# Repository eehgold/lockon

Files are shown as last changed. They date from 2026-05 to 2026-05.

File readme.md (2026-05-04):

# L.O.C.K.O.N
# Laser Optimized Capture & Kinetic Observation Node

## Objectif

LOCKON est une tourelle motorisee capable de :

- detecter une cible via vision par ordinateur
- suivre automatiquement la cible (tracking)
- orienter une camera sur 2 axes (pan / tilt)
- activer un laser lorsque la cible est verrouillee

---

## Fonctionnement

1. La camera envoie le flux video au PC
2. Le module de vision detecte la cible
3. Le programme calcule la position de la cible
4. Envoi des angles a l'Arduino
5. L'Arduino pilote les servos via le PCA9685
6. Le laser s'allume lorsque la cible est centree

---

## Architecture

## Materiel

### Vision
- Camera USB OV9732 (100 degres, 720p, global shutter)

### Mecanique
- Support pan-tilt aluminium 2 axes
- 2 servos 20 kg

### Electronique
- Arduino Nano (ATmega328)
- Driver PWM PCA9685 (16 canaux)
- Alimentation 5V 5A
- Module laser 5V (650 nm)
- Transistor NPN type 2N2222/BC337 ou MOSFET logique pour commuter le laser
- Resistance 1 kOhm pour la commande du transistor
- Resistance 10 kOhm optionnelle entre commande laser et GND pour garder le laser eteint au demarrage
- Condensateur 470 uF

### Divers
- Cables Dupont
- Visserie / entretoises

---

### Branchements

Etat actuel : l'Arduino est branche au PC en USB. Le PCA9685 est relie a
l'Arduino pour l'I2C et l'alimentation logique. La carte PCA9685 recoit aussi
une alimentation 5V cote servos.

```mermaid
flowchart LR
    PC[PC]
    ARD[Arduino Nano]
    PCA[PCA9685]
    PSU[Alimentation 5V externe]
    S1[Servo axe Y]
    S2[Servo axe X]
    Q1[Transistor/MOSFET]
    LASER[Module laser 5V]

    PC -->|USB| ARD

    ARD -->|A4 / SDA| PCA
    ARD -->|A5 / SCL| PCA
    ARD -->|GND| PCA
    ARD -->|+5V / VCC logique| PCA

    PSU -->|+5V / V+ servos| PCA
    PSU -->|GND commun| PCA

    PCA -->|Canal PWM 0 / axe Y| S1
    PCA -->|Canal PWM 1 / axe X| S2

    ARD -->|D7 via resistance 1k| Q1
    PSU -->|+5V| LASER
    LASER -->|fil noir / GND commute| Q1
    Q1 -->|GND commun| PSU
```

| Arduino Nano | PCA9685 | Role |
| --- | --- | --- |
| A4 | SDA | Donnees I2C |
| A5 | SCL | Horloge I2C |
| GND | GND | Masse commune |
| +5V | VCC | Alimentation logique du PCA9685 |

| Alimentation externe 5V | PCA9685 | Role |
| --- | --- | --- |
| +5V | V+ | Alimentation des servos |
| GND | GND | Masse commune avec Arduino/PCA |

### Branchement du laser

Le module laser a deux fils :

| Fil laser | Branchement recommande | Role |
| --- | --- | --- |
| Rouge | +5V de l'alimentation externe | Alimentation laser |
| Noir | Collecteur/drain du transistor | Masse commutee par l'Arduino |

Commande du transistor :

| Arduino Nano | Intermediaire | Role |
| --- | --- | --- |
| D7 | Resistance 1 kOhm puis base/gate transistor | Signal de commande laser |
| GND | Emetteur/source transistor et GND alimentation | Masse commune |

Avec un NPN type 2N2222/BC337 : fil noir du laser sur le collecteur, emetteur
sur GND, D7 vers la base via une resistance 1 kOhm. Avec un MOSFET logique :
fil noir du laser sur le drain, source sur GND, D7 vers la gate. Dans tous les
cas, le GND Arduino, le GND PCA9685 et le GND de l'alimentation 5V doivent etre
communs.

Ne pas alimenter un laser de courant inconnu directement depuis une broche de
l'Arduino. La broche D7 sert seulement a commander le transistor. Pour les
tests, garder le laser pointe vers une surface mate non reflechissante, jamais
vers les yeux ou un visage.

---

## Test et debug des servos

Le sketch `esp32_prog/esp32_prog.ino` est un sketch de diagnostic pour tester le
PCA9685 et les deux servos.

### Procedure

1. Brancher uniquement Arduino + PCA9685, sans servo.
2. Televerser le sketch Arduino.
3. Ouvrir le moniteur serie en `115200 bauds`.
4. Verifier que le message `PCA9685 detecte a l'adresse 0x40.` apparait.
5. Couper l'alimentation.
6. Brancher un seul servo sur le canal `0`.
7. Remettre l'alimentation 5V externe du PCA9685.
8. Verifier que le servo bouge entre centre, min et max.
9. Couper l'alimentation, puis brancher le deuxieme servo sur le canal `1`.
10. Relancer le test avec les deux servos.

### Points a verifier si rien ne bouge

- Le PCA9685 doit etre detecte sur l'I2C, normalement a l'adresse `0x40`.
- Si le moniteur serie affiche seulement l'en-tete puis plus rien, le programme
  bloque probablement pendant une transaction I2C. Verifier surtout `SDA`,
  `SCL`, `VCC`, `GND`, et retirer temporairement les servos.
- `GND Arduino`, `GND PCA9685` et `GND alimentation servos` doivent etre communs.
- Les servos ne doivent pas etre alimentes par le `5V` de l'Arduino.
- Le bornier `V+` du PCA9685 doit recevoir le `+5V` de l'alimentation externe.
- Le connecteur servo doit etre dans le bon sens : signal PWM, `V+`, `GND`.
- Tester d'abord un seul servo pour eviter une chute de tension.
- Si le servo grogne mais ne tourne pas, verifier l'alimentation 5V et le courant disponible.
- Si le moniteur serie affiche `PCA9685 absent`, verifier `A4/SDA`, `A5/SCL`, `VCC` et `GND`.

### Canaux utilises

| Canal PCA9685 | Role |
| --- | --- |
| 0 | Servo axe Y |
| 1 | Servo axe X |

---

## LOCKON v0.2 - Interface manuelle avec retour camera

Le script `lockon_gui.py` fournit une interface graphique simple pour piloter
les deux servos depuis le PC et afficher le retour de la camera USB.

### Lancement

```powershell
python -m pip install -r requirements.txt
python lockon_gui.py
```

### Fonctionnalites

- Affichage du flux camera dans l'encart `Video`.
- Demarrage automatique de la camera a l'ouverture de la GUI.
- Selection de l'index camera puis demarrage/arret manuel depuis la GUI.
- Detection de cible dans le flux video : `Main` avec le modele local
  `hand_landmarker.task`, ou `Tete` avec la cascade OpenCV integree.
- Overlay LOCKON : reticule central, boite/squelette de cible et compteur.
- Encart `Tracking` avec choix de cible `Rien`, `Main`, `Tete`, mode de vitesse
  `Normal` ou `Fast`, zone morte, gain de correction et prediction.
- Suivi automatique : la tourelle corrige `X/Y` pour ramener la cible au centre
  du reticule.
- Interface regroupee par encarts : `Video`, `Connexion`, `Controles`,
  `Parametres`, `Etat`.
- Connexion au port serie de l'Arduino.
- Affichage de 4 boutons directionnels.
- Pilotage a la souris via les boutons de l'interface.
- Pilotage au clavier avec les touches flechees.
- Affichage de `Pos X` et `Pos Y`.
- Parametre `Vitesse` saisissable puis applique avec le bouton `Envoyer`.
- Affichage de la vitesse appliquee dans la zone `Etat`.
- Bouton `CENTRE` pour revenir a `X=0`, `Y=0`.

La vitesse GUI vaut `50` par defaut et accepte une valeur de `1` a `500`. Cette limite vient de la
datasheet du MG996R, qui annonce environ `0.17 s / 60 degres` a `4.8V` et
`0.14 s / 60 degres` a `6V`.

Le suivi automatique est regle sur `Main` au demarrage. Pour couper totalement
le tracking, choisir `Rien` dans l'encart `Tracking`. Procedure conseillee :
connecter l'Arduino, cliquer `CENTRE`, verifier la detection dans la video, puis
choisir `Main` ou `Tete`. Les boutons manuels gardent la priorite pendant
l'appui. Le mode `Fast` augmente la correction par tick sans depasser les
limites servo.

L'option `Prediction` estime la vitesse de la cible entre deux detections et
oriente le tracking vers une position avancee de quelques millisecondes. Le
parametre `Avance ms` regle cette anticipation. Une valeur trop haute peut
faire depasser la cible ou provoquer des oscillations ; commencer autour de
`160 ms`, puis ajuster progressivement.

### Protocole serie

Le PC envoie des commandes texte a l'Arduino :

```text
POS x y
LASER 0
LASER 1
```

Exemple :

```text
POS 20 -10
LASER 1
```

La GUI v0.2 limite les positions envoyees de `-700` a `700` pour eviter de
forcer les servos en butee pendant les tests. L'Arduino convertit directement la
position en microsecondes autour du centre `1500us` :

```text
pulse servo = 1500us + position
```

Le sketch Arduino accepte encore la plage large historique, mais il vaut mieux
recalibrer axe par axe avant de remonter les limites dans la GUI.

La GUI comporte une option `Laser auto`, desactivee au demarrage. Quand elle est
armee, le PC envoie `LASER 1` seulement quand une cible `Main` ou `Tete` est
detectee et que son centre est dans la zone morte du reticule. Cela signifie que
la tourelle vise au bon endroit. Le PC envoie `LASER 0` quand la cible sort de
la zone morte, disparait, quand le tracking passe sur `Rien`, quand la camera
s'arrete ou lors de la deconnexion serie.

Pour le debug de branchement, la case `Laser force` envoie `LASER 1` meme sans
detection de cible. Elle permet de verifier au voltmetre que la broche `D7`
passe bien a environ `5V` par rapport au `GND`.

### Canaux v0.1

| Canal PCA9685 | Axe logiciel |
| --- | --- |
| 0 | Y |
| 1 | X |

### Controles v0.1

| Controle | Axe commande |
| --- | --- |
| Fleche haut | X + |
| Fleche bas | X - |
| Fleche gauche | Y - |
| Fleche droite | Y + |

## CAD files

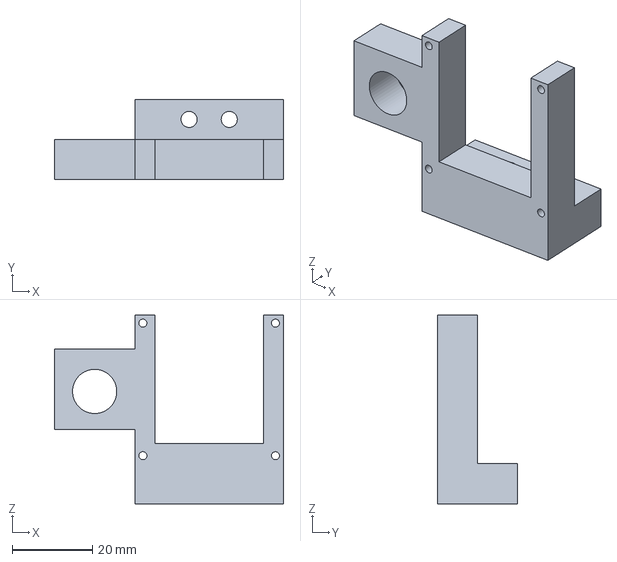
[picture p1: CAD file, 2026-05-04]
stls/cam_holdert.FCStd
57.0 x 20.0 x 47.0 mm

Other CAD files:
stls/cam_holdert-Corps.stl

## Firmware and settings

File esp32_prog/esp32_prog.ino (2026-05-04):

#include <Wire.h>
#include <Adafruit_PWMServoDriver.h>

const byte PCA9685_ADDRESS = 0x40;
const byte SERVO_Y_CHANNEL = 0;
const byte SERVO_X_CHANNEL = 1;
const byte LASER_PIN = 7;

const int SERVO_CENTER_US = 1500;
const int POSITION_MIN = -1120;
const int POSITION_CENTER = 0;
const int POSITION_MAX = 1240;

Adafruit_PWMServoDriver pwm = Adafruit_PWMServoDriver(PCA9685_ADDRESS);
bool pcaFound = false;
int currentX = POSITION_CENTER;
int currentY = POSITION_CENTER;
bool laserEnabled = false;

byte i2cProbe(byte address) {
  Wire.beginTransmission(address);
  return Wire.endTransmission();
}

bool i2cDevicePresent(byte address) {
  return i2cProbe(address) == 0;
}

void scanI2C() {
  Serial.println("Scan I2C en cours...");

  byte foundCount = 0;
  for (byte address = 1; address < 127; address++) {
    if (i2cDevicePresent(address)) {
      Serial.print("  Peripherique trouve a 0x");
      if (address < 16) {
        Serial.print("0");
      }
      Serial.println(address, HEX);
      foundCount++;
    }
  }

  if (foundCount == 0) {
    Serial.println("  Aucun peripherique I2C trouve.");
  }
}

void initPCA9685() {
  Serial.println("PCA9685 detecte a l'adresse 0x40.");

  pwm.begin();
  pwm.setOscillatorFrequency(27000000);
  pwm.setPWMFreq(50);
  delay(10);

  pwm.writeMicroseconds(SERVO_X_CHANNEL, SERVO_CENTER_US);
  pwm.writeMicroseconds(SERVO_Y_CHANNEL, SERVO_CENTER_US);
  Serial.println("Servos initialises au centre.");
  Serial.println("Pret. Commande attendue: POS x y");
}

int positionToPulse(int position) {
  position = constrain(position, POSITION_MIN, POSITION_MAX);
  return SERVO_CENTER_US + position;
}

void setTurretPosition(int x, int y) {
  currentX = constrain(x, POSITION_MIN, POSITION_MAX);
  currentY = constrain(y, POSITION_MIN, POSITION_MAX);

  pwm.writeMicroseconds(SERVO_X_CHANNEL, positionToPulse(currentX));
  pwm.writeMicroseconds(SERVO_Y_CHANNEL, positionToPulse(currentY));

  Serial.print("OK X=");
  Serial.print(currentX);
  Serial.print(" Y=");
  Serial.println(currentY);
}

void setLaser(bool enabled) {
  laserEnabled = enabled;
  digitalWrite(LASER_PIN, laserEnabled ? HIGH : LOW);
  digitalWrite(LED_BUILTIN, laserEnabled ? HIGH : LOW);
  Serial.print("OK LASER=");
  Serial.println(laserEnabled ? 1 : 0);
}

void handleSerialCommand(String command) {
  command.trim();
  command.toUpperCase();

  if (command.length() == 0) {
    return;
  }

  if (command == "CENTER") {
    setTurretPosition(POSITION_CENTER, POSITION_CENTER);
    return;
  }

  if (command == "LASER ON" || command == "LASER 1") {
    setLaser(true);
    return;
  }

  if (command == "LASER OFF" || command == "LASER 0") {
    setLaser(false);
    return;
  }

  if (command.startsWith("POS ")) {
    int firstSpace = command.indexOf(' ');
    int secondSpace = command.indexOf(' ', firstSpace + 1);
    if (secondSpace < 0) {
      Serial.println("ERR format attendu: POS x y");
      return;
    }

    int x = command.substring(firstSpace + 1, secondSpace).toInt();
    int y = command.substring(secondSpace + 1).toInt();
    setTurretPosition(x, y);
    return;
  }

  Serial.println("ERR commande inconnue");
}

void setup() {
  pinMode(LED_BUILTIN, OUTPUT);
  digitalWrite(LED_BUILTIN, LOW);
  pinMode(LASER_PIN, OUTPUT);
  digitalWrite(LASER_PIN, LOW);

  Serial.begin(115200);
  delay(2000);

  Serial.println();
  Serial.println("LOCKON - test PCA9685 + servos");
  Serial.println("Moniteur serie: 115200 bauds");
  Serial.println("Laser sur D7. Commandes: LASER 1 / LASER 0");

  Serial.println("Initialisation I2C...");
  Wire.begin();
#if defined(WIRE_HAS_TIMEOUT)
  Wire.setWireTimeout(25000, true);
  Serial.println("Timeout I2C actif.");
#else
  Serial.println("Timeout I2C non disponible avec ce core Arduino.");
#endif

  Serial.println("Recherche du PCA9685 a l'adresse 0x40...");
  byte pcaStatus = i2cProbe(PCA9685_ADDRESS);
  pcaFound = pcaStatus == 0;
  if (!pcaFound) {
    Serial.println("ERREUR: PCA9685 absent a l'adresse 0x40.");
    Serial.print("Code I2C: ");
    Serial.println(pcaStatus);
    Serial.println("Verifier A4/SDA, A5/SCL, VCC, GND et masse commune.");
    scanI2C();
    return;
  }

  initPCA9685();
}

void loop() {
  if (!pcaFound) {
    delay(3000);
    scanI2C();
    pcaFound = i2cDevicePresent(PCA9685_ADDRESS);
    if (pcaFound) {
      initPCA9685();
    }
    return;
  }

  if (Serial.available()) {
    String command = Serial.readStringUntil('\n');
    handleSerialCommand(command);
    delay(10);
  }
}

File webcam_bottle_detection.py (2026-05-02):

import argparse
import sys
import time

import cv2

try:
    import mediapipe as mp
except ImportError as exc:  # pragma: no cover - handled at runtime
    raise SystemExit(
        "Le package 'mediapipe' est manquant. Installe les dependances avec :\n"
        "python -m pip install -r requirements.txt"
    ) from exc


WINDOW_NAME = "LOCKON - Webcam Hand Detection"
MODEL_URL = (
    "https://storage.googleapis.com/mediapipe-models/"
    "hand_landmarker/hand_landmarker/float16/1/hand_landmarker.task"
)


def parse_args() -> argparse.Namespace:
    parser = argparse.ArgumentParser(
        description="Affiche le flux webcam et les boites de detection des mains."
    )
    parser.add_argument(
        "--camera-index",
        type=int,
        default=0,
        help="Index de la webcam a utiliser (defaut: 0).",
    )
    parser.add_argument(
        "--width",
        type=int,
        default=1280,
        help="Largeur demandee a la webcam (defaut: 1280).",
    )
    parser.add_argument(
        "--height",
        type=int,
        default=720,
        help="Hauteur demandee a la webcam (defaut: 720).",
    )
    parser.add_argument(
        "--camera-fps",
        type=int,
        default=30,
        help="FPS demandes a la webcam (defaut: 30).",
    )
    parser.add_argument(
        "--process-width",
        type=int,
        default=640,
        help="Largeur utilisee pour la detection (defaut: 640).",
    )
    parser.add_argument(
        "--process-height",
        type=int,
        default=360,
        help="Hauteur utilisee pour la detection (defaut: 360).",
    )
    parser.add_argument(
        "--window-width",
        type=int,
        default=1600,
        help="Largeur initiale de la fenetre OpenCV (defaut: 1600).",
    )
    parser.add_argument(
        "--window-height",
        type=int,
        default=900,
        help="Hauteur initiale de la fenetre OpenCV (defaut: 900).",
    )
    parser.add_argument(
        "--max-hands",
        type=int,
        default=2,
        help="Nombre maximum de mains a detecter (defaut: 2).",
    )
    parser.add_argument(
        "--min-detection-confidence",
        type=float,
        default=0.5,
        help="Seuil minimal pour detecter une main (defaut: 0.5).",
    )
    parser.add_argument(
        "--min-tracking-confidence",
        type=float,
        default=0.5,
        help="Seuil minimal pour suivre une main (defaut: 0.5).",
    )
    parser.add_argument(
        "--model-path",
        default="hand_landmarker.task",
        help="Chemin local du modele MediaPipe (defaut: hand_landmarker.task).",
    )
    parser.add_argument(
        "--detect-every",
        type=int,
        default=1,
        help="Effectue la detection une frame sur N et reutilise le dernier resultat (defaut: 1).",
    )
    parser.add_argument(
        "--no-detect",
        action="store_true",
        help="Affiche uniquement le flux webcam pour mesurer le FPS sans detection.",
    )
    return parser.parse_args()


def ensure_model(model_path: str) -> str:
    import urllib.request
    from pathlib import Path

    path = Path(model_path)
    if path.exists():
        return str(path)

    print(f"Telechargement du modele de main vers '{path}'...")
    path.parent.mkdir(parents=True, exist_ok=True)
    urllib.request.urlretrieve(MODEL_URL, path)
    return str(path)


def open_camera(index: int, width: int, height: int, fps: int) -> cv2.VideoCapture:
    camera = cv2.VideoCapture(index, cv2.CAP_DSHOW)
    if not camera.isOpened():
        camera = cv2.VideoCapture(index)

    if not camera.isOpened():
        raise RuntimeError(
            f"Impossible d'ouvrir la webcam a l'index {index}. "
            "Verifie l'index ou qu'aucune autre application ne l'utilise."
        )

    camera.set(cv2.CAP_PROP_FOURCC, cv2.VideoWriter_fourcc(*"MJPG"))
    camera.set(cv2.CAP_PROP_FRAME_WIDTH, width)
    camera.set(cv2.CAP_PROP_FRAME_HEIGHT, height)
    camera.set(cv2.CAP_PROP_FPS, fps)
    return camera


def landmark_to_pixel(landmark, width: int, height: int) -> tuple[int, int]:
    x = min(max(int(landmark.x * width), 0), width - 1)
    y = min(max(int(landmark.y * height), 0), height - 1)
    return x, y


def draw_hand_overlay(frame, hand_landmarks, handedness_label: str) -> None:
    height, width = frame.shape[:2]
    points = [landmark_to_pixel(landmark, width, height) for landmark in hand_landmarks]

    for connection in mp.tasks.vision.HandLandmarksConnections.HAND_CONNECTIONS:
        start = points[connection.start]
        end = points[connection.end]
        cv2.line(frame, start, end, (255, 180, 0), 2, cv2.LINE_AA)

    for point in points:
        cv2.circle(frame, point, 4, (0, 220, 0), -1)

    x_values = [point[0] for point in points]
    y_values = [point[1] for point in points]
    x1 = max(min(x_values) - 20, 0)
    y1 = max(min(y_values) - 20, 0)
    x2 = min(max(x_values) + 20, width - 1)
    y2 = min(max(y_values) + 20, height - 1)

    cv2.rectangle(frame, (x1, y1), (x2, y2), (0, 220, 0), 2)
    cv2.rectangle(frame, (x1, max(0, y1 - 28)), (x1 + 110, y1), (0, 220, 0), -1)
    cv2.putText(
        frame,
        handedness_label,
        (x1 + 6, y1 - 8),
        cv2.FONT_HERSHEY_SIMPLEX,
        0.55,
        (0, 0, 0),
        2,
        cv2.LINE_AA,
    )

    center_x = (x1 + x2) // 2
    center_y = (y1 + y2) // 2
    cv2.circle(frame, (center_x, center_y), 4, (0, 220, 0), -1)


def draw_hud(frame, hand_count: int, fps: float, camera_fps: float) -> None:
    height, width = frame.shape[:2]
    center_x = width // 2
    center_y = height // 2

    cv2.line(frame, (center_x - 20, center_y), (center_x + 20, center_y), (0, 180, 255), 1)
    cv2.line(frame, (center_x, center_y - 20), (center_x, center_y + 20), (0, 180, 255), 1)

    status = f"Mains detectees: {hand_count}"
    cv2.putText(
        frame,
        status,
        (20, 35),
        cv2.FONT_HERSHEY_SIMPLEX,
        0.8,
        (255, 255, 255),
        2,
        cv2.LINE_AA,
    )
    cv2.putText(
        frame,
        "CPU",
        (20, 70),
        cv2.FONT_HERSHEY_SIMPLEX,
        0.7,
        (255, 255, 255),
        2,
        cv2.LINE_AA,
    )
    cv2.putText(
        frame,
        f"FPS: {fps:.1f}",
        (20, 105),
        cv2.FONT_HERSHEY_SIMPLEX,
        0.7,
        (255, 255, 255),
        2,
        cv2.LINE_AA,
    )
    cv2.putText(
        frame,
        f"Cam FPS: {camera_fps:.1f}",
        (20, 140),
        cv2.FONT_HERSHEY_SIMPLEX,
        0.7,
        (255, 255, 255),
        2,
        cv2.LINE_AA,
    )
    cv2.putText(
        frame,
        "Q pour quitter",
        (20, height - 20),
        cv2.FONT_HERSHEY_SIMPLEX,
        0.6,
        (255, 255, 255),
        2,
        cv2.LINE_AA,
    )
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
